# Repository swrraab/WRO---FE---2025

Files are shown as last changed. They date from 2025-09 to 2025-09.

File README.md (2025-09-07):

# **2025 WRO Future Engineers Competition** 
# Team **Pink Boba Pearls** 🌸🧋🫧
This repository is for the 2025 WRO Future Engineeers competition. We are a team of 2 high-school girls from Ontario, Canada 🇨🇦 We are passionate about all things engineering - specifically computer science 💻 and space 🚀 

This repository has the below folders
1. `docs` - Contains the Engineering Documentation
2. `models` - Contains STL files we used for our 3D prints 
2. `other` - Contains miscellanous files used for README.md
3. `schemes` - Contains our connection schematic and power distribution schematic
4. `src` - Contains our source code 
5. `t-photos` - Contains team photos
6. `v-photos` - Contains vehicle photos
7. `videos` - Contains links to vehicle demo youtube videos`

## The Hardware
1. **Microcontroller - [Microbit v2](https://microbit.org/buy/bbc-microbit-single/):** Together with the Siyeenove Mshield Pinout board - For controlling drive motor and steering servo motor based on input from the Raspberry Pi
2. **Single Board Computer (SBC) - [Raspberry Pi 4 Model B 2GB](https://www.raspberrypi.com/products/raspberry-pi-4-model-b/):** Vehicle mobility control

Other parts used
1. Sainsmart 160 degree wideangle 5PM camera for Raspberry Pi
2. Lego Technic pieces - to build the chassis
3. 12V Lithium battery power supply - Power supply for all the components
4. 12v to 5V Step-down converter - To supply power to Raspberry Pi and Microbit
5. L298N Motor Driver - To drive the 9V Lego DC motor
6. 9V Lego Motor
7. SG90 Micro Servo Motor
8. Various cables for power connections to the devices, USB cable for serial connection between Microbit and Raspberry Pi, and wires to transmit data from Microbit to the motors.  

Refer to the component schematic to connect all the above hardware together to make the car

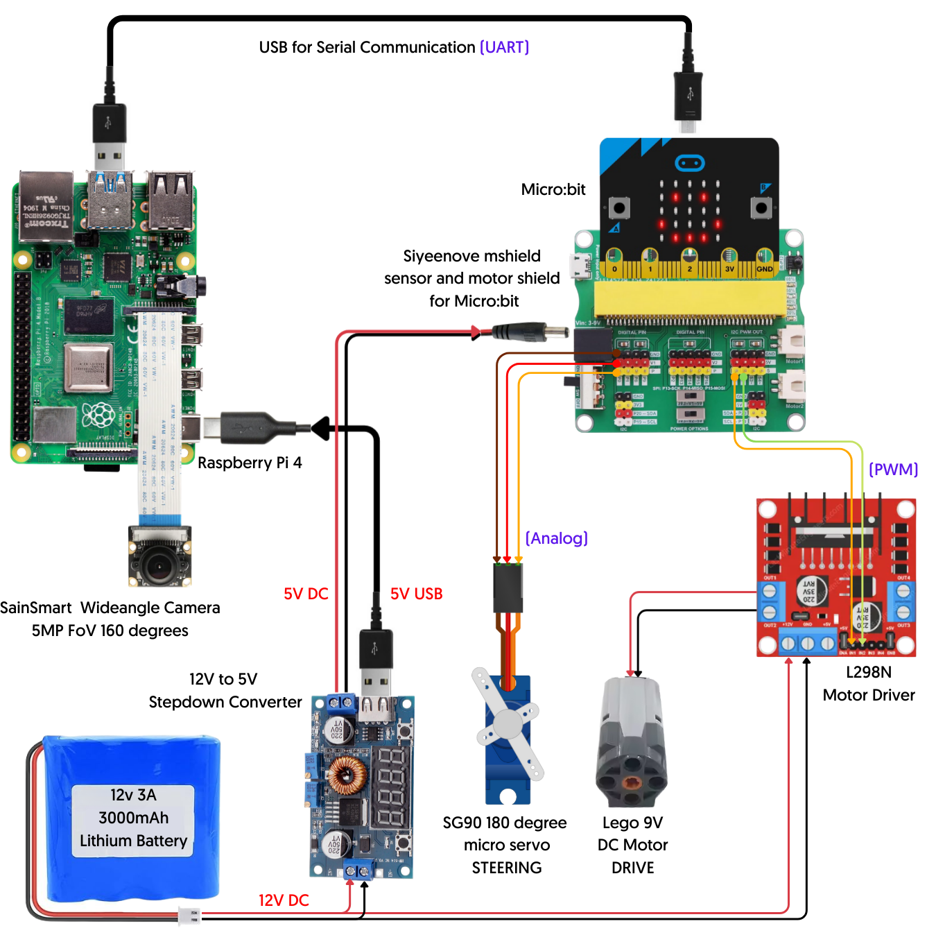
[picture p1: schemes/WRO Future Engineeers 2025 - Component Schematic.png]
Component Schematic


## The Software

There are 2 important programs that make the car run

* `obs_ch.py` - loaded to the Raspberry Pi to process the vision input from the camera. 
  * It is part of the crontab, which launches the program when the Raspberry Pi boots up 
  * Once it is ready, it sends a signal to the Microbit indicating that it is ready. If there is a problem with the Python Program loading, the signal to the Microbit will not be sent which will allow the user to fix the program. 
  * Then it listens to the Microbit's A button to be pressed to start the car which starts calculating and transmitting DC motor speed and Servo turn data to the Microbit. 
  * As the car runs, the program reads visual data from the camera frame by frame and processes it using proportional-derivative controller (https://en.wikipedia.org/wiki/PID_controller) to get the servo turn values, which is transmitted to the Microbit in real-time to control the cars turns
  * The program has 2 distinct vision processing logic inside it
    1. For the open run, it looks at the walls and uses PD control to keep the car between the walls
    2. For the obstacle run, it looks at the color blocks and uses PD control to turn the car to avoid the blocks. 
  * Detailed explanation of the code is provided in the engineering documentation

* `pi2mb_motors_control.py` - loaded to the Microbit to drive the pi2mb_motors_control
  * As soon as it starts, it initializes the motor speed to 0 and servo direction to 90 (which keeps the car straight)
  * It awaits signal from the Raspberry Pi to confirm it has started successfully. When it receives the confirmation, it displays an 'S' on the LED array
  * When the user presses the 'A' button, it transmits a 'go' signal to the Raspberry Pi and awaits acknowledgement from the Raspberry Pi. When the acknowledgement is received, it displays a '+' on the LED array indicating that the car has started.
  * As the car runs, Raspberry Pi transmits the servo steering turn data and DC motor speed data as byte stream  which the Microbit will convert to numerical data, and split to integer values to be used for motor control
  * The servo turn angle is sent as analog signal to the servo motor directly. The 5V input required by the Servo is supplied by the Siyeenove Mshield board.
  * The speed data is sent as PWM signal to the L298N motor driver which uses the PWM signal and the power input from the 12V battery to drive the 9V DC motor. 
  * If the user wants to stop the car (and reset its values so the car can run again), they can simply press the 'A' button again which will signal the Raspberry Pi to stop the loop that processes vision data. This will display a minus '-' on the LED array.
  * If the user wants to kill the car (completely end the program), they can press the 'B' button which will signal the Raspberry Pi to exit the Python program

## Loading the software on to the hardware
Below section explains how to load each program on to their respective hardwares

**Getting `obs_ch.py` to run on the Raspberry Pi**

* Follow the Raspberry Pi **[Getting Started page](https://www.raspberrypi.com/documentation/computers/getting-started.html)** and follow all the instructions to get the OS distribution loaded and Raspberry Pi booted up
* `Tip` - Ensure you follow the instruction at the tail end of the above page to setup the **Raspberry Pi Connect". This will allow you to remotely connect to your Raspberry Pi with your laptop over Wifi. Otherwise, a separate monitor, HDMI cable, keyboard and mouse will be required every time you connect the Raspberry Pi. 
* When you access the Raspberry Pi, install a good Python editor like Geany or Thonny. It is possible to install Visual Studio Code, but we had performance issues since our Raspberry Pi only had 2GB RAM
* We used Picamera2 libraries to access the camera. The instructions to follow are all over the place. Follow these instructions carefully to get the camera setup. 
  * Access Raspberry Pi and open the terminal window
  * [Update all the software](https://www.raspberrypi.com/documentation/computers/os.html#update-software) running on the Raspberry Pi. You may need to do this every few weeks 
  * Picamera2 libraries would be preinstalled as part of the full software update. However, run ``sudo apt install -y python3-picamera2` on the terminal to install the libraries, if they are not installed. If they were installed this will NOT redo it. [Detailed instructions here](https://datasheets.raspberrypi.com/camera/picamera2-manual.pdf)
  * Now, we need to configure the settings to use the Sainsmart Wideangle camera which uses the Omnivision 5647 sensor. 
    * Open the firmware config by entering the following command on the terminal `sudo nano /boot/firmware/config.txt`
    * Change `camera_auto_detect=1` to `camera_auto_detect=0`
    * Under the `[all]` section, add the line `dtoverlay=ov5647`
    * Press `Ctrl+x` to save the file and exit the program
  * Test the camera with one of these commands - `rpicam-hello` or `libcamera-hello`
* Download the [`obs_ch.py`](/src/obs_ch.py) file from the `src` folder
* Ensure you can run this program by opening terminal and running `python obs_ch.py`. This should start running the program. If it does not, open the file and check if `DRAW` variable is set to `True` to troubleshoot.

* To automatically run this program when Raspberry Pi boots up, it needs to be part of the crontab. Follow these instructions to set it up
  * Open the crontab with the command `sudo crontab -e`
  * Add the python program to run upon bootup by adding this statement to the end of the crontab `@reboot /usr/bin/python3 </path/to>/obs_ch.py >/dev/null 2>&1 &`
  `Tip` - The above will redirect the standard print output and errors to `/dev/null` which is not useful if you want to access them. If you want debug print messages to be saved, ensure you create a log file with the command `sudo touch /dev/cronlog` and adding this file path to the above crontab statement instead. 

* Now you are all setup. If you reboot your Raspberry Pi, `obs_ch.py` file will start running. If it is not, check the `/dev/cronlog` for error messages to troubleshoot the problem.

**Getting `pi2mb_motors_control.py` to run on the Microbit**

* Note that the Microbit should be physically connected to the device you are using to upload the code, with a micro USB cable. It can be connected either to your workstation, or your Raspberry Pi. 
* The instructions to load this program is relatively easier because we followed the simpler method by accessing https://makecode.microsoft.org using the Chrome browser on the Raspberrry Pi (or any browser on your laptop). There are alternatives to use the Thonny Python editor or Visual Studio code, but we found it too tedious just to get the Microbit connected to take the program. 
* Open a new Python program on makecode by clicking on **New Project**. Give it a name and select **Python Only** in the code options drop-down. Then click on **Create** button.
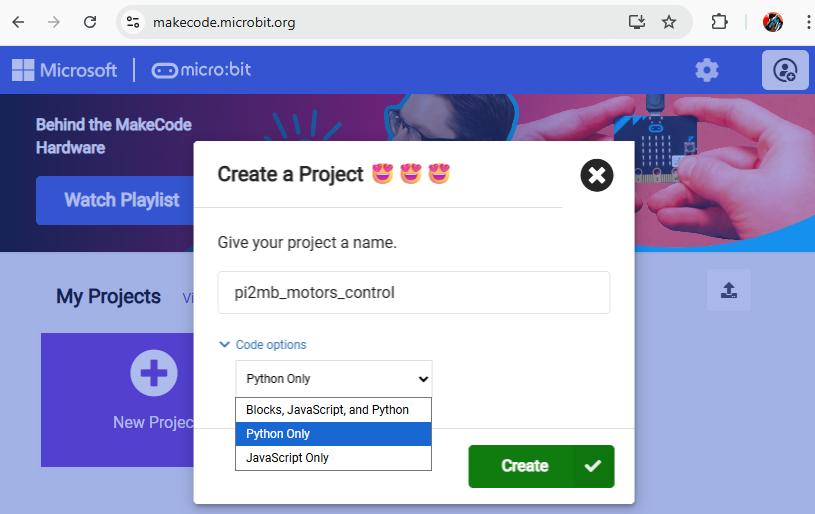
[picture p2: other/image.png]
Creating a new Python program on makecode

* When the program is open, copy the entire content of [`pi2mb_motors_control.py`](/src/pi2mb_motors_control.py) from the `src` folder, on to the new Python program on makecode.
* Click on **Download** button to deploy the binary code to Microbit. You will hear an audible beep when the program is loaded to indicated the Microbit has successfully received the code (***Note:*** The audible beep is not a default behavior. We included the beep as a way for the Microbit to convey its readiness everytime it starts or is reset)
* That is all! When connected to the Raspberry Pi over USB cable (as shown in the [schematic](/schemes/WRO%20Future%20Engineeers%202025%20-%20Component%20Schematic.png) and powered on, the program will be ready to transmit to and receive data from the Raspberry Pi and move your car.

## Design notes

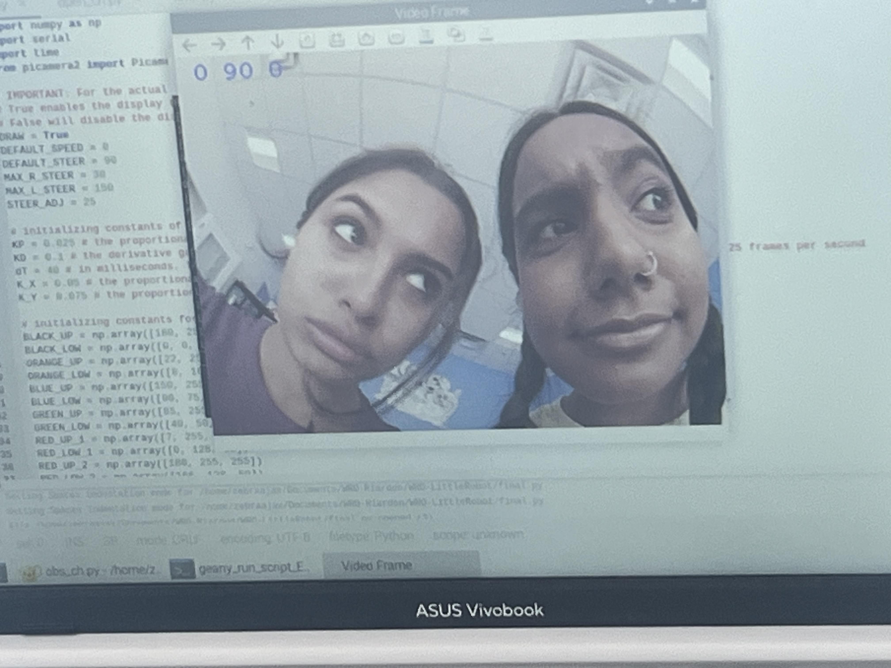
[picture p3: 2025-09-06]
t-photos/funnypic.jpg

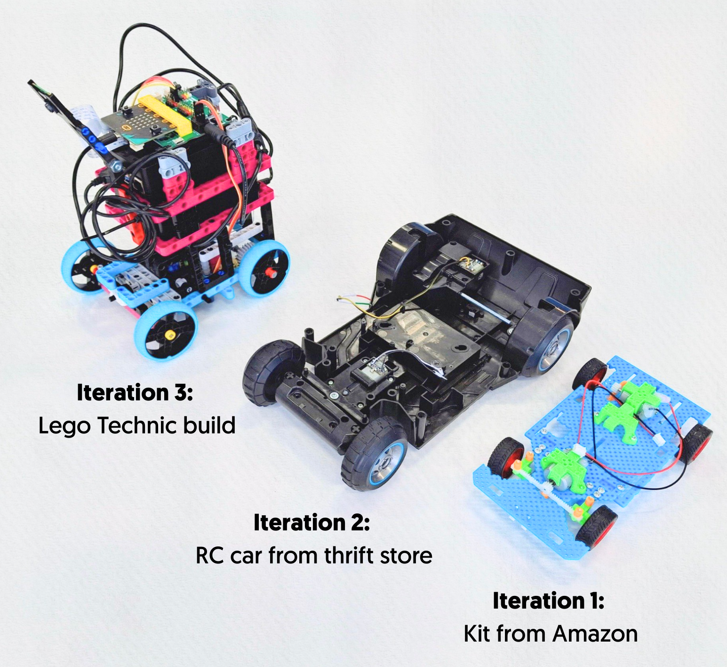
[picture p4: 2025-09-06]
v-photos/Car evolution iterations.png

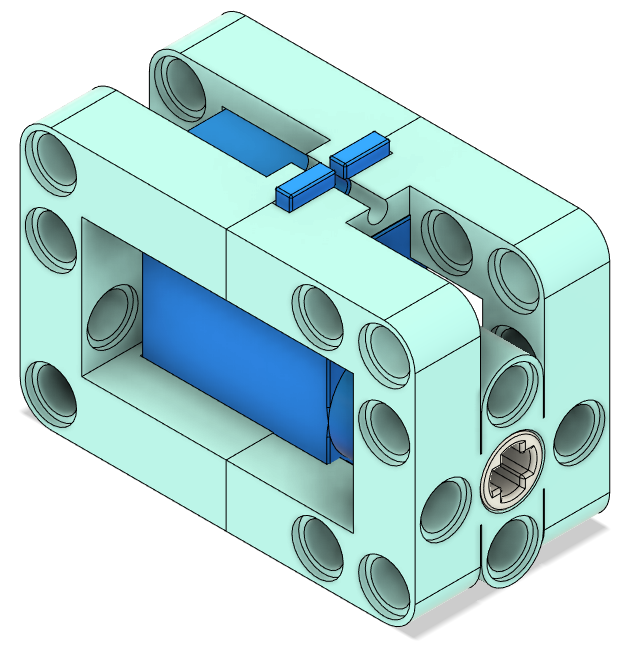
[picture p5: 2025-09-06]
models/s90 Servo Mount v1.PNG

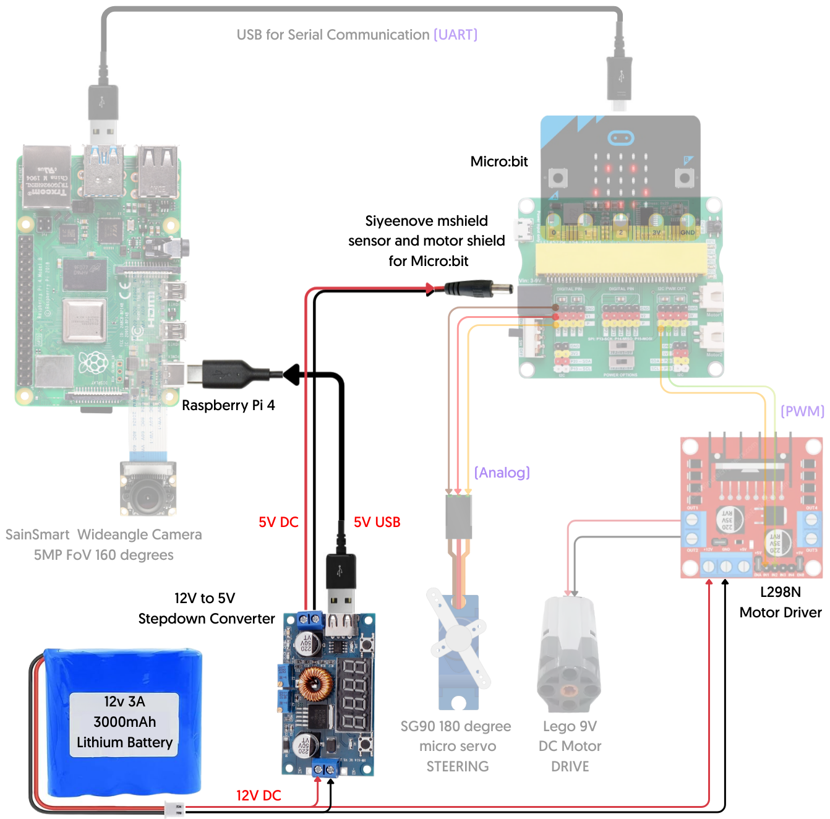
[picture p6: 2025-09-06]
schemes/WRO Future Engineeers 2025 - Power Management.png

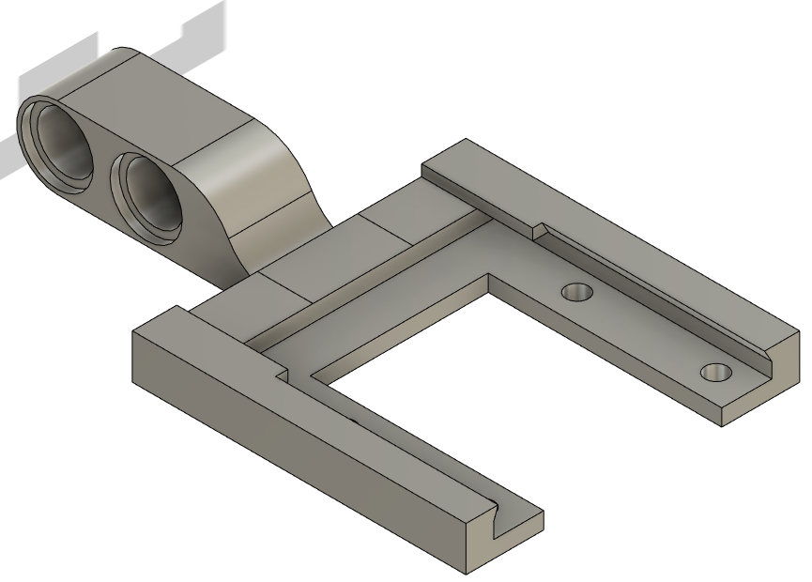
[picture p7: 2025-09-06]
models/Camera Mount.png

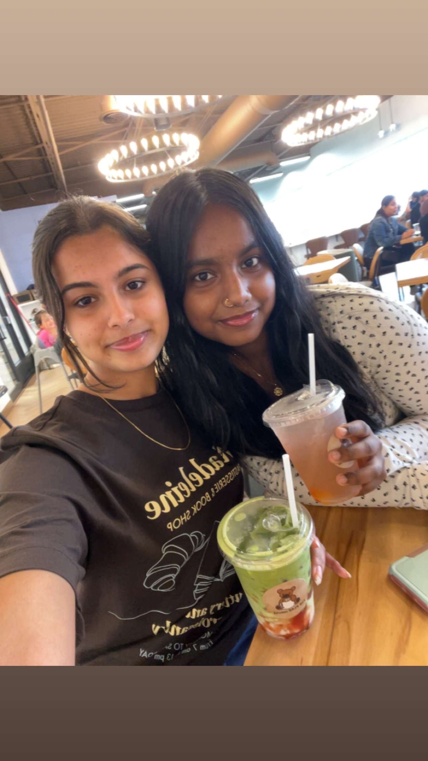
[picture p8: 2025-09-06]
t-photos/officialpic.JPG

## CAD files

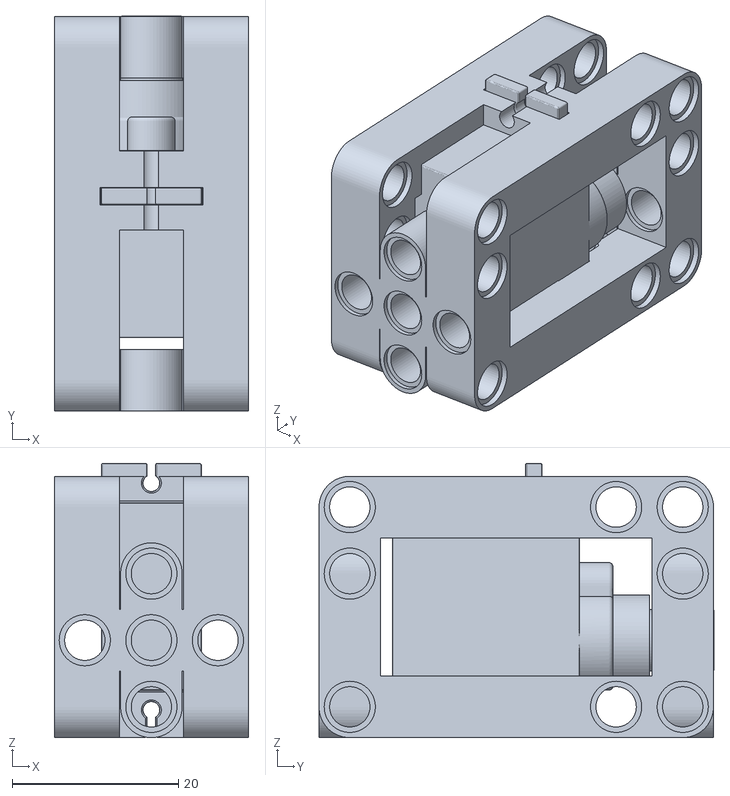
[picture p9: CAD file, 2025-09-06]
models/s90 Servo Mount v1.stl
23.4 x 47.5 x 33.0

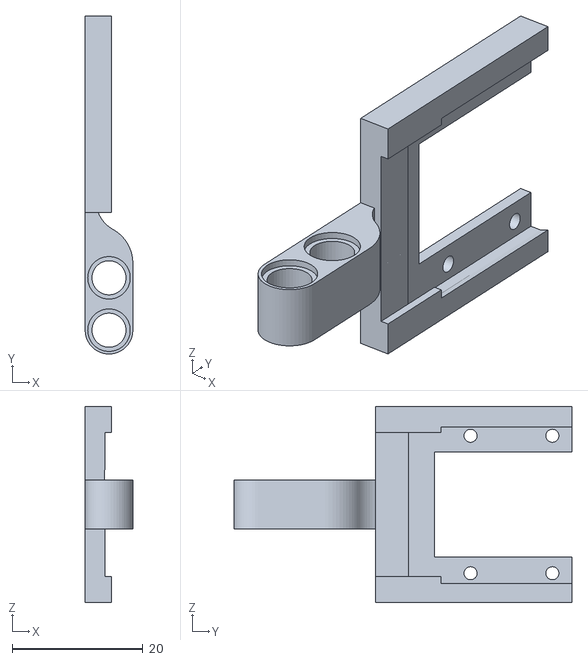
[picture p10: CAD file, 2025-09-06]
models/Camera Mount.stl
7.29 x 51.6 x 30.0

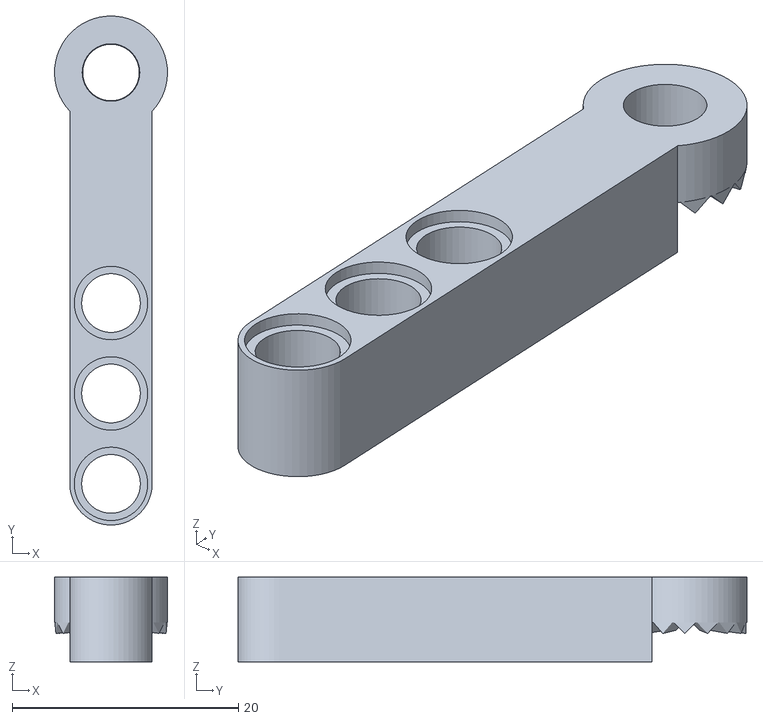
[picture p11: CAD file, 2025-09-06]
models/Camera Mount Extension.stl
10.00 x 45.0 x 7.50

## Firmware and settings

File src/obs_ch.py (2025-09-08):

# import RobotAPI as Rapi
import cv2
import numpy as np
import serial
import time
from picamera2 import Picamera2

# IMPORTANT: For the actual run, please change the DRAW value to False
# True enables the display to show on screen and also display the contour borders
# False will disable the display so the cron will not fail looking for a display
DRAW = True
DEFAULT_SPEED = 110
DEFAULT_STEER = 90
MAX_R_STEER = 15
MAX_L_STEER = 165
STEER_ADJ = 25

# initializing constants of ratio for controllers
KP = 0.025 # the proportional gain, a tuning parameter for walls
KD = 0.1 # the derivative gain, a tuning parameter for walls
dT = 40 # in milliseconds. This is the time step for each frame processing based on measured value of average 25 frames per second
K_X = 0.15 # the proportional gain, a tuning parameter for X coordinate of the blocks
K_Y = 0.12 # the proportional gain, a tuning parameter for Y coordinate of the blocks

# initializing constants for hsv
BLACK_UP = np.array([180, 255, 70])  # for walls
BLACK_LOW = np.array([0, 0, 0])
ORANGE_UP = np.array([22, 255, 255])  # for orange lines
ORANGE_LOW = np.array([8, 160, 40])
BLUE_UP = np.array([150, 255, 255])  # for blue lines
BLUE_LOW = np.array([90, 75, 70])
GREEN_UP = np.array([85, 255, 255])  # for green blocks
GREEN_LOW = np.array([40, 50, 50])
RED_UP_1 = np.array([5, 255, 255])   # for red blocks
RED_LOW_1 = np.array([0, 128, 50])
RED_UP_2 = np.array([180, 255, 255])
RED_LOW_2 = np.array([170, 128, 50])

# initializing constants for coordinates of areas in the image - 640 x 480
X1_1_PD = 610  # for walls
X2_1_PD = 640
X1_2_PD = 0
X2_2_PD = 30
Y1_PD = 200 #200
Y2_PD = 480

X1_LINE = 280  # for counting lines
X2_LINE = 360
Y1_LINE = 400
Y2_LINE = 480

X1_CUB = 40  # for block detection
X2_CUB = 600
Y1_CUB = 200 #160
Y2_CUB = 440

X1_STOP = 0

Y1_CUB_BLACK = 400
BLACK = False

class Frames:  # clsss for areas on the picture
    def __init__(self, img, x_1, x_2, y_1, y_2, low, up):  # init gains coordinates of the area, and hsv boders
        self.x_1 = x_1  # initializing variables in class
        self.x_2 = x_2
        self.y_1 = y_1
        self.y_2 = y_2
        self.up = up
        self.low = low

        self.contours = 0
        self.frame = 0
        self.hsv = 0
        self.mask = 0
        self.frame_gaussed = 0

        self.update(img)

    def update(self, img):  # function for updating the image
        # getting the needed area on the image and outlining it
        cv2.rectangle(img, (self.x_1, self.y_1), (self.x_2, self.y_2), (0, 255, 220), 1)

        self.frame = img[self.y_1:self.y_2, self.x_1:self.x_2]
        self.frame_gaussed = cv2.GaussianBlur(self.frame, (1, 1), cv2.BORDER_DEFAULT)  # blurring the image

        self.hsv = cv2.cvtColor(self.frame_gaussed, cv2.COLOR_BGR2HSV)  # turning the image from bgr to hsv

    def find_contours(self, n=0, to_draw=True, color=(0, 0, 255), min_area=50, red_dop=0):  # function for selecting
        # the contours, it gets, the needed borders of hsv, if the borders should be drawn, color of the outlining,
        # minimum area of the contour, and if it is used for red blocks
        self.mask = cv2.inRange(self.hsv, self.low[n], self.up[n])  # getting the mask
        if red_dop == 1:
            mask_1 = cv2.inRange(self.hsv, self.low[n + 1], self.up[n + 1])
            self.mask = cv2.bitwise_or(self.mask, mask_1)

        contours, _ = cv2.findContours(self.mask, cv2.RETR_TREE, cv2.CHAIN_APPROX_NONE)  # getting contours
        r_contours = []
        for i in contours:  # outlining and selecting only big enough contours
            if cv2.contourArea(i) > min_area:
                r_contours.append(i)
                if to_draw:
                    cv2.drawContours(self.frame, i, -1, color, 2)

        return r_contours  # returning contours


def pd():  # function of proportional–derivative controller for walls
    global pd_r, pd_l, KD, KP, err_old, timer_flag, time_turn, tim
    global flag_left, flag_right, time_green, time_red, steer # needed global variables for this function

    steer_adj = 0  # getting the addition to pd, to compensate the angle of the camera
    if direction == 'CW':
        steer_adj = 5
    if direction == 'CCW':
        steer_adj = 5

    # find all the black countours on the right of the car = area_1
    contours = pd_r.find_contours(to_draw=DRAW, color=(255, 255, 255))  # getting the contours for right area
    area_r = map(cv2.contourArea, contours)  # getting the area of the biggest contour`
    if contours:
        area_r = max(area_r)
    else:
        area_r = 0

    # find all the black countours on the left of the car = area_2
    contours = pd_l.find_contours(to_draw=DRAW, color=(255, 255, 255))  # same for 2_nd area
    area_l = map(cv2.contourArea, contours)
    if contours:
        area_l = max(area_l)
    else:
        area_l = 0

        
    # ~ # print(f"Right: {area_r} Left: {area_l} Difference: {area_l-area_r}")

    err = area_r - 1000 - area_l # counting the error and the final value of pd
    steer = DEFAULT_STEER + steer_adj + int(err * KP + ((err - err_old) // dT * KD))
    err_old = err

    if steer > MAX_L_STEER:  # limiting the left turn of servo
        steer = MAX_L_STEER
    if steer < MAX_R_STEER:  # limiting the right turn for servo
        steer = MAX_R_STEER    
        
    return(steer)

# ~ def pd():  # function of proportional–derivative controller for walls
    # ~ global pd_1, pd_2, KD, KP, err_old, timer_flag, time_turn, tim
    # ~ global flag_left, flag_right, time_green, time_red, steer, after_block  # needed global variables for this function

    # ~ steer_adj = 0  # getting the addition to pd, to compensate the angle of the camera
    # ~ if direction == 'CW':
        # ~ steer_adj  = 5
    # ~ if direction == 'CCW':
        # ~ steer_adj = 5

    # ~ contours = pd_r.find_contours(to_draw=DRAW, color=(255, 255, 255))  # getting the contours for 1_st area
    # ~ area_r = map(cv2.contourArea, contours)  # getting the area of the biggest contour
    # ~ if contours:
        # ~ area_r = max(area_r)
    # ~ else:
        # ~ area_r = 0

    # ~ contours = pd_l.find_contours(to_draw=DRAW, color=(255, 255, 255))  # same for 2_nd area
    # ~ area_l = map(cv2.contourArea, contours)
    # ~ if contours:
        # ~ area_l = max(area_l)
    # ~ else:
        # ~ area_l = 0
        
    # ~ print(f"Right: {area_r} Left: {area_l} Difference: {area_r-area_l}")

    # ~ err = area_r - area_l # counting the error and the final value of pd
    # ~ steer = DEFAULT_STEER + steer_adj + int(err * KP + ((err - err_old) // dT * KD))
    # ~ err_old = err

    # ~ if area_l != 0 and area_r == 0:  # if there is no wall in one of ares, turning to the max to needed side
        # ~ flag_right = True  # changing the flag or turning
        # ~ if not timer_flag:  # resetting the timer of turning
            # ~ print("r_timer")
            # ~ if time.time() - time_green < 0.2:  # if the turn, right after the inner block, turn to the max
                # ~ after_block = True
                # ~ if direction == 'CW':
                    # ~ time_turn = time.time() - 5
                    # ~ print("gcw")
            # ~ else:
                # ~ time_turn = time.time()
            # ~ timer_flag = True

        # ~ if time.time() - time_turn > 0.5:
            # ~ steer = 30

        # ~ else:
            # ~ steer = 55

    # ~ elif area_r != 0 and area_l == 0:  # same as the previous
        # ~ flag_left = True
        # ~ if not timer_flag:
            # ~ if time.time() - time_red < 0.2:
                # ~ after_block = True
                # ~ if direction == 'CCW':
                    # ~ time_turn = time.time() - 5
            # ~ else:
                # ~ time_turn = time.time()

            # ~ timer_flag = True

        # ~ if time.time() - time_turn > 0.5:
            # ~ steer = 150
        # ~ else:
            # ~ steer = 125

    # ~ elif area_r == 0 and area_l == 0:  # if there's no wall in any area, turn to the same side as before
        # ~ if flag_right:
            # ~ if time.time() - time_turn > 0.5:
                # ~ steer = 30
            # ~ else:
                # ~ steer = 55

        # ~ elif flag_left:
            # ~ if time.time() - time_turn > 0.5:
                # ~ steer = 150
            # ~ else:
                # ~ steer = 125

    # ~ else:  # else resetting the flags
        # ~ after_block = False
        # ~ flag_left = False
        # ~ flag_right = False
        # ~ timer_flag = False

    # ~ if steer > 150:  # limiting the turning of servo
        # ~ steer = 150
    # ~ elif steer < 30:  # limiting the max turning for servo
        # ~ steer = 30
    # ~ print(steer)
    # ~ return steer  # returning controlling influence of pd


def pd_block(color):  # function of proportional–derivative controller for blocks
    global direction, K_X, K_Y, frame, time_red, time_green, block

    if color == 'green':  # getting the contours depending on the color
        countors = block.find_contours(to_draw=DRAW, color=(0, 255, 0), min_area=600)
    elif color == 'red':
        countors = block.find_contours(1, DRAW, min_area=600, red_dop=1)
    else:
        print('color error')
        return -1  # if the color is not right, return -1

    if countors:
        countors = max(countors, key=cv2.contourArea)  # if there is contours, getting the biggest of them
        x, y, w, h = cv2.boundingRect(countors)  # getting the coordinates of the contour
        x_ctr = x + w // 2 
        y_btm = y + h

        # If the color is green, the target X coordinate should be to the left edge of the rectangle
        if color == 'green':
            time_green = time.time()
            x_tgt = block.x_2 - block.x_1 # This represents the right edge of the rectangle - X coordinate would be 560 (as measured by X2 being 600 - X1 being 40)
        elif color == 'red':  # If the color is red, the target X coordinate should be to the right edge of the rectangle
            time_red = time.time()
            x_tgt = 0 # This represents the left edge of the rectangle - X coordinate would be 0

        err_x = round((x_tgt - x_ctr) * K_X, 3)  # error for x coordinate
        if color == 'green': # error for y coordinate
            err_y = round((y_btm - 50) * K_Y, 3)
        elif color == 'red':
            err_y = round((100 - y_btm) * K_Y, 3)
        err_block = int(err_y + err_x)  # getting the error for both coordinates
                
        print(f'color: {color}, x: {x}, y: {y}, w: {w}, h: {h}, x_tgt: {x_tgt}, x_ctr: {x_ctr}, y_btm: {y_btm}, err_x: {err_x}, err_y: {err_y}, err_block: {err_block}')
        if color == 'green':  # printing the error on the image
            frame = cv2.putText(frame, str(err_block), (20, 60),
                                cv2.FONT_HERSHEY_PLAIN, 2, (0, 255, 0), 2)
        else:
            frame = cv2.putText(frame, str(err_block), (500, 60),
                                cv2.FONT_HERSHEY_PLAIN, 2, (0, 0, 255), 2)

        return err_block  # returning the error

    return -1  # if there's no blocks in the area, return -1


def restart():  # function for resetting all the variables
    global orange, blue, steer, err_old, tim, time_orange, time_blue, start_flag, stop_flag, time_turn, time_green, time_red, time_speed
    global pause_flag, flag_line_blue, flag_line_orange, direction, time_stop, flag_left, flag_right, timer_flag

    orange = 0
    blue = 0

    timer_flag = False

    steer = DEFAULT_STEER
    speed = 0
    err_old = 0

    tim = time.time()
    time_orange = time.time() - 5
    time_blue = time.time() - 5
    time_turn = time.time() - 5
    time_green = time.time() - 2
    time_red = time.time() - 2
    time_speed = time.time() + 200
    time_stop = time.time()

    start_flag = False
    stop_flag = False
    reverse_flag = False
    pause_flag = False
    flag_left = False
    flag_right = False
    flag_line_orange = False
    flag_line_blue = False

    direction = ''


# Establish Serial connection to the Microbit over USB
ser = serial.Serial(
    port='/dev/ttyACM0',  # Replace ttyS0 with ttyAM0 for Pi1,Pi2,Pi0
    baudrate=115200,
    stopbits=serial.STOPBITS_ONE
)
ser.bytesize = serial.EIGHTBITS
ser.timeout  = 1

ser.reset_input_buffer()
ser.flushInput()
ser.flushOutput()

if not ser.isOpen():
    ser.open()
    print("***** Serial connection to Microbit Open *****")

orange = 0  # variables, for counting lines
blue = 0

steer = DEFAULT_STEER  # variables for pd
err_old = 0
speed = 0

# initializing timers
tim = time.time()  # for finish
time_orange = time.time() - 5  # for counting orange lines
time_blue = time.time() - 5  # for counting blue lines
time_turn = time.time() - 5  # for turns
time_green = time.time() - 2  # for green blocks
time_red = time.time() - 2  # for red blocks
time_speed = time.time() + 200  # for slowing down at the start(optional)
time_stop = time.time()  # for stopping the robot

# initializing flags
timer_flag = False  # for resetting other variables only once
start_flag = False
stop_flag = False  # for stopping the robot
reverse_flag = False
pause_flag = False  # for pausing the robot
flag_left = False  # for tracking turns to the left
flag_right = False  # for tracking turns to the right
flag_line_orange = False  # for tracking orange lines
flag_line_blue = False  # for tracking blue lines
after_block = False  # for tracking turns after blocks

direction = ''  # direction variable

print("Heyyy....")

cv2.startWindowThread()

picam2 = Picamera2()
picam2.configure(picam2.create_preview_configuration(main={"format": 'XRGB8888', "size": (640,480)}))
picam2.start()

frame = picam2.capture_array("main")

if frame is None:
    print("No image captured - main")

# initializing objects for different areas
pd_r = Frames(frame, X1_1_PD, X2_1_PD, Y1_PD, Y2_PD, [BLACK_LOW], [BLACK_UP])  # for the right wall
pd_l = Frames(frame, X1_2_PD, X2_2_PD, Y1_PD, Y2_PD, [BLACK_LOW], [BLACK_UP])  # for the left wall
line = Frames(frame, X1_LINE, X2_LINE, Y1_LINE, Y2_LINE, [BLUE_LOW, ORANGE_LOW], [BLUE_UP, ORANGE_UP])  # for counting
# lines
# for detection blocks
block = Frames(frame, X1_CUB, X2_CUB, Y1_CUB, Y2_CUB, [GREEN_LOW, RED_LOW_1, RED_LOW_2], [GREEN_UP, RED_UP_1, RED_UP_2])
black_wall_stop = Frames(frame, X1_CUB+180, X2_CUB-180, Y1_CUB_BLACK, Y2_CUB, [BLACK_LOW], [BLACK_UP]) # Frame to see the wall in block Frame

# variables for counting fps
time_fps = time.time()
fps = 0
fps_last = 0

ser.write("ssssss\n".encode('utf-8')) # sending message to Microbit

while True:  # main loop
    # ~ if time.time() - time_speed > 3:  # checking of the speed raising
        # ~ speed_def = 35
    # ~ # resetting controlling influence and speed
    fps += 1
#    frame = robot.get_frame(wait_new_frame=1)  # getting image from camera
    
    # ~ print("Left area: " + area_l + "Right area:" + area_r)
    
    frame = picam2.capture_array("main")
    if frame is None:
        print("No image captured")
        break
    
    mb_msg = ser.read_all().decode("utf-8")
    if mb_msg == 'go':
        if start_flag:
            restart()
            speed = 0
            ser.write("stoppp\n".encode('utf-8'))  # sending message to Microbit
        else:
            start_flag = True
            speed = DEFAULT_SPEED
            ser.write("startt\n".encode('utf-8'))  # sending message to Microbit 
            
    # ~ if mb_msg == 'quit':
        # ~ ser.write('190200\n'.encode('utf-8'))
        # ~ time.sleep(0.1)  
        # ~ print("Ciao...")
        # ~ ser.write('squitt\n'.encode('utf-8'))
        # ~ time.sleep(0.1)
        # ~ break 

    if (start_flag):
        # find all the black contours in the stop wall frame
        black_wall_stop.update(frame)
        contours_stop = black_wall_stop.find_contours(0, DRAW, min_area=1000, color=(255, 255, 255))
        if contours_stop:
            contours_stop = max(contours_stop, key=cv2.contourArea)
            area_stop = cv2.contourArea(contours_stop)
            if area_stop > 1000:
                speed = 0
                reverse_flag = True
                time_stop = time.time()
                
        while reverse_flag:
            if time.time() - time_stop < 0.9:  # reversing for 0.5 seconds
                speed = -50
                
                if direction == "CW":
                    steer = 140
                elif direction == "CCW":
                    steer = 40
   
                mesg = str(steer + 100) + str(speed + 200) + '\n'  # forming the message for pyboard
                print(mesg)
                ser.write(mesg.encode('utf-8'))  # sending message to pyboard
            
            else:
                reverse_flag = False
                speed = DEFAULT_SPEED       
        
        block.update(frame)  # updating block area

        u_red = pd_block('red')  # getting controlling influence for red blocks
        u_green = pd_block('green')  # getting controlling influence for green blocks
        if u_green != -1 or u_red != -1:
            steer = 90 + max(u_green, u_red, key=abs)  # if there are blocks, counting final controlling influence

        # if there are no blocks, the robot will drive between walls
        else:
            pd_r.update(frame)  # updating wall areas
            pd_l.update(frame)
            steer = pd()  # counting controlling influence

        line.update(frame)  # updating line-counting area
        contours_blue = line.find_contours(0, DRAW, min_area=500)  # getting bue and orange areas
        contours_orange = line.find_contours(1, DRAW, min_area=500, color=(255, 255, 0))

        if contours_blue:  # if there is blue contour, checking, if the line is new, and adding it
            contours_blue = max(contours_blue, key=cv2.contourArea)
            ar = cv2.contourArea(contours_blue)
            if ar > 10:
                if not flag_line_blue and time.time() - time_blue > 1:
                    if not direction:
                        direction = 'CCW'
                    blue += 1
                    if blue == 1 and orange == 0:
                        time_speed = time.time()
                    print(f'direction: {direction} --- blue: {blue} --- orange: {orange}')
                    time_blue = time.time()  # resetting timer for blue lines
                    tim = time.time()  # resetting timer for stopping
                flag_line_blue = True
        else:
            flag_line_blue = False

        if contours_orange:  # same as for blue line
            contours_orange = max(contours_orange, key=cv2.contourArea)
            ar = cv2.contourArea(contours_orange)
            if ar > 10:
                if not flag_line_orange and time.time() - time_orange > 1:
                    if not direction:
                        direction = 'CW'
                    orange += 1
                    if orange == 1 and blue == 0:
                        time_speed = time.time()
                    time_orange = time.time()
                    print(f'direction: {direction} --- orange: {orange} --- blue: {blue}')
                    tim = time.time()
                flag_line_orange = True
        else:
            flag_line_orange = False

        if (max(orange, blue) > 11 and time.time() - tim > 1.2) or stop_flag:  # checking if the robot must stop
            if not stop_flag:
                time_stop = time.time()
            if time.time() - time_stop < 0.3:  # braking for 0.3 seconds
                speed = -50
            else:  # stopping the robot
                speed = 0
            steer = 90
            mesg = str(steer + 100) + str(speed + 200) + '\n'  # forming the message for pyboard
            # print(mesg)
            ser.write(mesg.encode('utf-8'))  # sending message to pyboard
            stop_flag = True

        if pause_flag:  # checking if the robot is paused
            steer = DEFAULT_STEER
            speed = 0
        
        if time.time() - time_fps > 1:  # counting fps
            time_fps = time.time()
            fps_last = fps
            fps = 0

    if not stop_flag:  # checking if robot is not stopped/breaking
        frame = cv2.putText(frame, ' '.join([str(speed), str(steer), str(fps_last)]), (20, 30),
                            cv2.FONT_HERSHEY_PLAIN, 2, (255, 0, 0), 2)  # printing parameters on the image
        mesg = str(steer + 100) + str(speed + 200) + '\n'  # sending message to pyboard
        # print(mesg)
        ser.write(mesg.encode('utf-8'))  # sending message to pyboard
    
    if DRAW:
        cv2.imshow("Video Frame", frame)

        key = cv2.waitKey(1) & 0xFF
            
        if key != -1:
            if key == ord('q'):
                ser.write('190200\n'.encode('utf-8'))
                print("Ciao...")
                break
            elif key == ord('p'):  # if s is clicked, pausing the robot
                pause_flag = True
            elif key == ord('g'):  # if g is clicked unpausing the robot
                pause_flag = False
            elif key == ord('r'):  # if r is clicked restarting the robot
                restart()

ser.close()
cv2.destroyAllWindows()

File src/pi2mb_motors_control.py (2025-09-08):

from microbit import *
import music
import mShield

# Play music to indicate the Microbit is active
music.play(music.tone_playable(Note.C, music.beat(BeatFraction.WHOLE)), music.PlaybackMode.UNTIL_DONE)

# Initilize serial connection parameters
serial.redirect_to_usb()
serial.set_baud_rate(BaudRate.BAUD_RATE115200)
serial.set_rx_buffer_size(7)

# Set the Siyeenove Shield S ports to PWM control
mShield.set_s1_to_s4_type(mShield.S1ToS4Type.PWM)

# Initialize default values
deg = 90
speed = 0

# Set servo to align straight
pins.servo_write_pin(AnalogPin.P0, deg)

# Set drive motor speed to zero
mShield.extend_pwm_control(mShield.PwmIndex.S3, 0)
mShield.extend_pwm_control(mShield.PwmIndex.S4, speed)

# When Button A is pressed send the "go" signal to R-Pi
# In the R-Pi this either starts the car or stops the car
# based on the current state of the car
# Feeback from the R-Pi is handled in the while loop below
def on_button_pressed_a():
    basic.pause(100)
    serial.write_string("go")
    
input.on_button_pressed(Button.A, on_button_pressed_a)

# def on_forever():
while True:
    try:
        # Read serial uart data from Raspberry Pi
        data_in = serial.read_until(serial.delimiters(Delimiters.NEW_LINE))
        
        # Depending on the feedback from the R-Pi actions, display
        # patterns on the screen to indicate car status
        if (data_in[0] == "s"):
            if data_in == "startt":
                basic.show_leds("""
                    . . . . .
                    . . # . .
                    . # # # .
                    . . # . .
                    . . . . .
                    """)
            elif data_in == "stoppp":
                basic.show_leds("""
                    . . . . .
                    . . . . .
                    . # # # .
                    . . . . .
                    . . . . .
                    """)
            elif data_in == "ssssss":
                basic.show_leds("""
                    . # # # #
                    # . . . .
                    . # # # .
                    . . . . #
                    # # # # .
                    """)
      
        else:
            # decode the input data to separate servo turn degrees, and motor speed values
            deg, speed = int(data_in[:3])-100, int(data_in[3:6])-200
    
            # Send turn angle to servo
            pins.servo_write_pin(AnalogPin.P0, deg)

            if speed < 0:
                # Send speed as PWM value to the 9v DC motor                
                mShield.extend_pwm_control(mShield.PwmIndex.S4, 0)
                mShield.extend_pwm_control(mShield.PwmIndex.S3, abs(speed))

            else:
                # Send speed as PWM value to the 9v DC motor               
                mShield.extend_pwm_control(mShield.PwmIndex.S3, 0)
                mShield.extend_pwm_control(mShield.PwmIndex.S4, speed)
        
    except:
        basic.show_leds("""
            # . . . #
            . . . . .
            . . # . .
            . . . . .
            # . . . #
            """)
        pass

# basic.forever(on_forever)

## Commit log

2025-07-15 Component Schematic
2025-09-06 Delete schemes/WRO Future Engineeers 2025 - Component Schematic.png
    Deleting old version of schematics
2025-09-06 Add files via upload
    Added newest versions of schematics
2025-09-06 Add files via upload
    Added current 3D files
    [Camera Mount Extension.stl, Camera Mount.stl, s90 Servo Mount v1.stl]
2025-09-08 Added functionality for the robot to stop when it is in collision course with a wall and to reverse for 5 seconds
    [obs_ch.py, pi2mb_motors_control.py]
2025-10-10 Update README.md to include Python libraries used in Raspberry Pi
2025-10-10 Update README.md - Bill of Materials
2025-10-10 schematic images
2025-10-10 Early Schematic.png
2025-10-10 Uploaded Schematic Diagrams
2025-10-10 Image processing frames
